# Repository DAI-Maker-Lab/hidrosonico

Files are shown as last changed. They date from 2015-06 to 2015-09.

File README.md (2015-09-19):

# Hidrosónico
<i>Hidrosónico</i> is a stream gauge using a <a href="http://www.maxbotix.com/documents/HRXL-MaxSonar-WR_Datasheet.pdf">MaxSonar HRXL MB7369</a> sonar rangefinder, a <a href="http://www.seeedstudio.com/wiki/Seeeduino-Stalker_v3">Seeeduino Stalker v3</a> Arduino-compatible microcontroller platform, and an <a href="https://learn.adafruit.com/adafruit-fona-mini-gsm-gprs-cellular-phone-module/overview">Adafruit FONA 800</a> GSM module. It reads the distance between the sensor (specifically from where the housing meets the threading) and the water's surface directly below and sends this data at specified intervals to cloud-based storage, SMS, and/or email as determined by the user. It was designed to aid in collection of hydrological data and for flood early warning in developing countries. This version integrates a rain gauge at the request of the recipient. 

The code provided sends data to data.sparkfun.com as the cloud service but it could be easily adapted to any other provider. Please note the places in the code that are marked for user-specific input.

This is a beta unit and we will be making changes as a result of the data and experiences we are collecting from pilot installations in Honduras, as well as feedback from on-the-ground partners like CODEM-DC in Tegucigalpa.

All code and hardware files are being made available under open source licensing. If you use it, please let us know (robert_ryan-silva[at]dai.com), and if you improve it, please share!

##Bill of Materials

Links to vendors are provided for convenience and not meant to imply an endorsement of that vendor; most of the items are available from other sources, and most components can be adequately substituted with equivalents. We have no connections nor receive any benefit from any of the vendors indicated.

###Required:
<ul>
<li><b><a href="http://www.seeedstudio.com/depot/Seeeduino-Stalker-v3-p-1882.html?cPath=6_7">Seeeduino Stalker v3</a></b>. Most Arduino-compatible microcontrollers will work, but most will require additional circuitry to charge the battery from a solar cell and for use of the real-time clock. Some Arduino-compatibles will require some pin changes (though the Arduino Uno and its equivalents should be fine).</li>
<li><b><a href="https://www.adafruit.com/products/1946">Adafruit FONA 800</a> and <a href="https://www.adafruit.com/products/1859">antenna</a></b>. The FONA 808 would also work, but would require some wiring changes and would not fit on the circuit board as designed. Any GSM module that is not based on the SIMCOM SIM 800 series chips would need code changes to work properly.</li>
<li><b><a href="http://www.amazon.com/Maxbotix-MB7369-HRXL-MaxSonar-WRM/dp/B00A7YHBT2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">Maxbotix MaxSonar HRXL MB7369</a></b>.</li>
<li><b>A solar panel</b>. We use <a href="https://www.adafruit.com/products/500">these</a>. We have not found any panels that terminate in the JST connector that the Stalker takes, so a <a href="https://www.adafruit.com/products/261">JST connector</a> is highly recommended; <a href="http://www.amazon.com/gp/product/B0076AY6J8?psc=1&redirect=true&ref_=oh_aui_search_detailpage">Scotchlok butt connectors</a> or similar (inside the enclosure, of course) make connecting the JST connector to the solar panel quite easy.</li>
<li><b>A lithium-ion battery</b>. We use <a href="https://www.adafruit.com/products/1781">these</a>.</li>
</ul>

###Optional:
<ul>
<li><b>Rain gauge</b>. You can collect rainfall data at the same site for a minimal additional cost with the addition of a rain gauge. The <i>Hidrosónico</i> code in the repository records data from a simple <a href="https://www.argentdata.com/catalog/product_info.php?products_id=168">Argent Data Systems rain gauge</a>. You'll need two 1K ohm resistors and a pair of 1N148 diodes to wire it to the microcontroller; an RJ-11 jack <a href="https://www.sparkfun.com/products/132">like this one from Sparkfun</a> will make this easier to work with, but you could strip the wires and solder them directly.</li>
<li><b>Circuit board</b>. Eagle files for a custom circuit board to accommodate the FONA and the optional rain gauge are included in the repository. You could cut this on a CNC machine or have it fabricated by a vendor like <a href="https://oshpark.com/">OSH Park</a>. It isn't strictly necessary -- you could wire the FONA directly -- but we found in practice that installation can be a violent process and connections coming loose is a real possibility. It is recommended especially if you intend to implement the rain gauge.</li>
<li><b>Interior structure</b>. The repository includes a STL file for an interior frame to hold the various internal components stable inside a 4 x 4 x 2 inch PVC junction box <a href=http://www.homedepot.com/p/Carlon-4-in-x-4-in-x-2-in-PVC-Junction-Box-5-Pack-E989NNJ-CAR/202206114">like this one</a>. We cut a 1-inch hole in the faceplate of the junction box and use PVC cement to attach a threaded 3/4-inch coupling <a href="http://www.homedepot.com/p/Carlon-3-4-in-PVC-Coupling-E940E-CTN/100404040">like this one</a>. Again, it's not necessary, but it does keep things from banging around much during installation. Additional holes must be drilled to accommodate the solar panel and the rain gauge. We use plumber's putty to fill the gaps around the cabling.</li>
<li><b>Mounts</b>. You'll want to mount the solar panel and optional rain gauge somehow. The repository includes SVG files for mounts that we have used with the PVC junction boxes. We cut these from sheet metal using waterjet cutters or 3.5mm polypropylene using laser cutters; both have the advantage of being easily bendable (with heat, in the case of polypropylene) to the desired angle. For those without access to fancy CNC cutters, the repository also includes a template for a simpler sheet metal solar panel mount that could be cut with aviation shears or other sheet metal cutting implements.</li>
<li><b><a href="http://www.seeedstudio.com/depot/Grove-4-pin-Female-Jumper-to-Grove-4-pin-Conversion-Cable-5-PCs-per-PAck-p-1020.html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">Grove <-> female jumper cable</a></b>. Makes connecting the MaxBotix to the Stalker very easy indeed.</li>
<li><b>An Xbee 802.15.4 radio</b> will allow you to reprogram the unit from nearby without physically opening the housing, which can be a serious hassle depending on where the unit is mounted.</li>

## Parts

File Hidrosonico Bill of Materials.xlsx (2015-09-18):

Hidrosonico Bill of Materials
Part | Manufacturer Part Number | Vendor Information | Unit Cost | Pieces per Unit | Total Cost
3D Printed Frame | n/a | Custom (PLA) | $0.36 | 1 | $0.36
3M Scotchlok IDC Butt Connector (UY2-3M) | 610373752064 | http://smile.amazon.com/gp/product/B0076AY6J8?psc=1&redirect=true&ref_=oh_aui_detailpage_o00_s00 | $0.10 | 2 | $0.21
Adafruit FONA 800 Mini (uFL) | 1946 | https://www.adafruit.com/products/1946 | $39.95 | 1 | $39.95
Carlon 4"x2" PVC junction box | E989NNJ-CAR | http://www.homedepot.com/p/Carlon-4-in-x-2-in-Junction-Box-E989NNJ-CAR/100404097 | $6.88 | 1 | $6.88
Generic 1kOhm resistors | EP5141K00 | http://smile.amazon.com/gp/product/B00B5R8950?psc=1&redirect=true&ref_=oh_aui_detailpage_o00_s00 | $0.18 | 2 | $0.36
Generic 1N4148 diodes | 1N4148FS-ND | http://www.digikey.com/product-search/en?keywords=1N4148FS-ND | $0.10 | 2 | $0.20
Grove 4-pin Female Jumper to Grove 4-pin Conversion Cable | 110990028 | http://www.seeedstudio.com/depot/Grove-4-pin-Female-Jumper-to-Grove-4-pin-Conversion-Cable-5-PCs-per-PAck-p-1020.html | $0.78 | 1 | $0.78
LiPo battery | 1781 | https://www.adafruit.com/products/1781 | $9.95 | 1 | $9.95
Maxbotix Sonar | MB7369 HRXL-MaxSonar-WRM | http://www.maxbotix.com/Ultrasonic_Sensors/MB7369.htm | $109.95 | 1 | $109.95
Mini GSM/Cellular Quad-Band Antenna - 2dBi SMA Plug | 1859 | https://www.adafruit.com/products/1859 | $4.95 | 1 | $4.95
PCB | n/a | Custom (OSH Park) | $6.60 | 1 | $6.60
Rain gauge | n/a | https://www.argentdata.com/catalog/product_info.php?products_id=168 | $15.00 | 1 | $15.00
Rain gauge mount | n/a | Custom (polypropylene) |  | 1 | $0.00
RJ11 jack | PRT-00132 | https://www.sparkfun.com/products/132 | $1.25 | 1 | $1.25
Scotch Heavy Duty Fasteners | RFD7091 | http://smile.amazon.com/gp/product/B00347A8GM?psc=1&redirect=true&ref_=oh_aui_detailpage_o00_s00 | $2.71 | 1 | $2.71
Seeed Studio Seeeduino Stalker v3 | 102010017 | http://www.seeedstudio.com/depot/Seeeduino-Stalker-v3-p-1882.html?cPath=6_7 | $39.00 | 1 | $39.00
SMA to uFL/u.FL/IPX/IPEX RF Adapter Cable | 851 | https://www.adafruit.com/products/851 | $3.95 | 1 | $3.95
Solar panel (6V 3.4W) | 500 | https://www.adafruit.com/products/500 | $39.00 | 1 | $39.00
Solar panel mount | n/a | Custom (polypropylene) |  | 1 | $0.00
Xbee 802.15.4 1MW w/wire antenna | XB24-AWI-001 | http://www.digikey.com/product-detail/en/XB24-AWI-001/XB24-AWI-001-ND/935965 | $19.00 | 1 | $19.00
Grand Total |  |  |  |  | $300.09

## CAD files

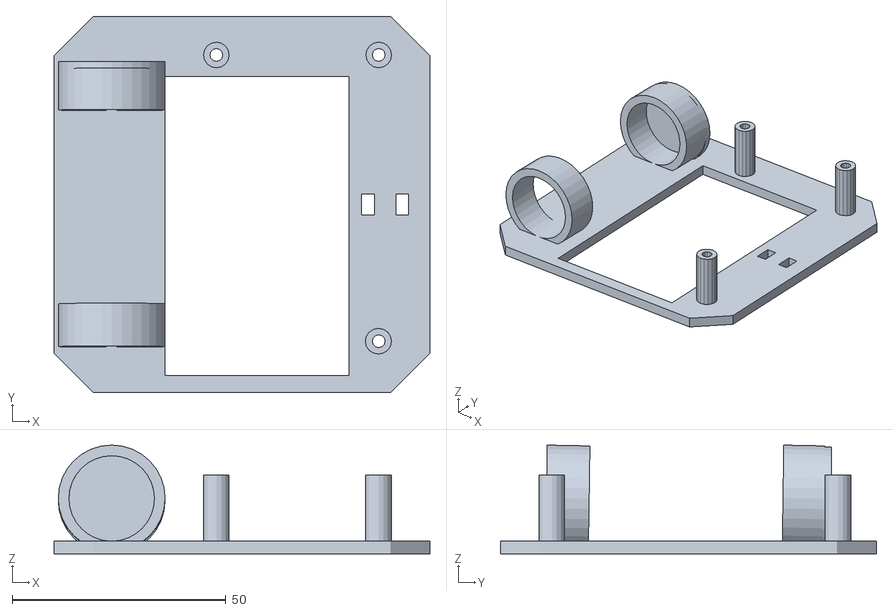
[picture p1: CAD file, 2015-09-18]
hidrosonico_interior_frame.stl
88.0 x 88.0 x 25.5

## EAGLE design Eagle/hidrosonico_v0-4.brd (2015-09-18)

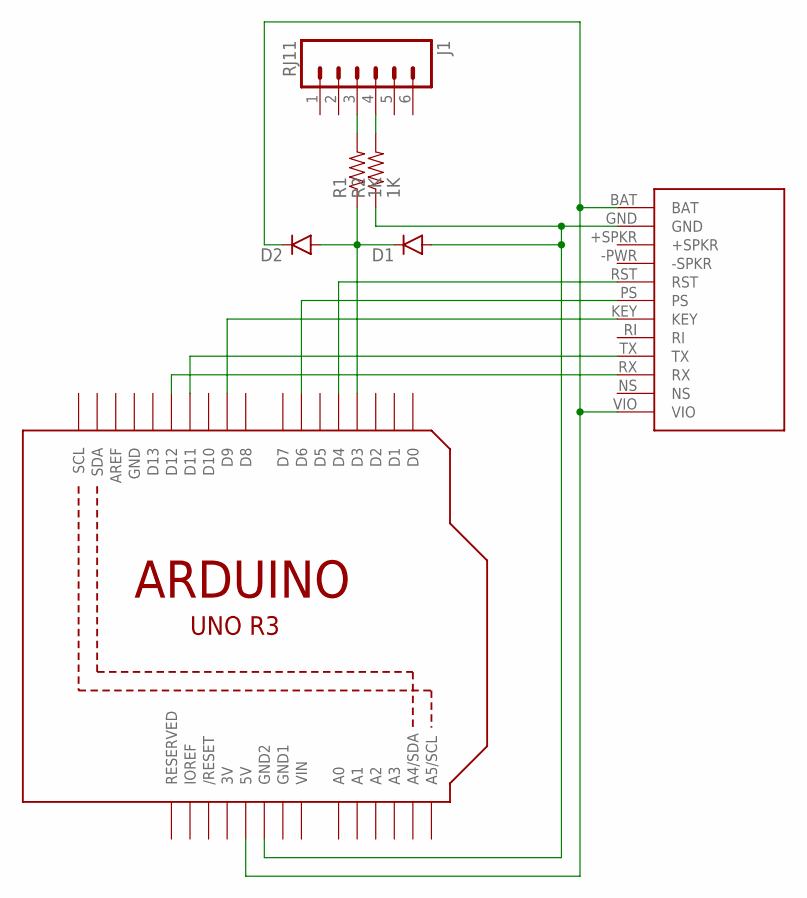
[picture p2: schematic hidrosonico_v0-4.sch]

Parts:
D1, D2: DIODE1N4148; DIODE-1N4148
J1: RJ11; RJ11-6
R1, R2: 1K; AXIAL-0.5
U2: ARDUINOR3-DIMENSION; ARDUINOR3
U$1: ADAFRUIT_FONA800; FONA

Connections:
3V: U2.3V
GND: D1.A, R2.P$1 (1), U2.GND, U2.GND2, U$1.GND
GND1: U2.GND1
unnamed: U2.D4, U$1.RST
unnamed: U2.D6, U$1.PS
unnamed: U2.D9, U$1.KEY
unnamed: U2.D11, U$1.TX
unnamed: U2.D12, U$1.RX
unnamed: J1.3, R1.P$2 (2)
unnamed: D1.C, D2.A, R1.P$1 (1), U2.D3
unnamed: J1.4, R2.P$2 (2)
VCC+: D2.C, U2.5V, U$1.BAT, U$1.VIO
VIN: U2.VIN

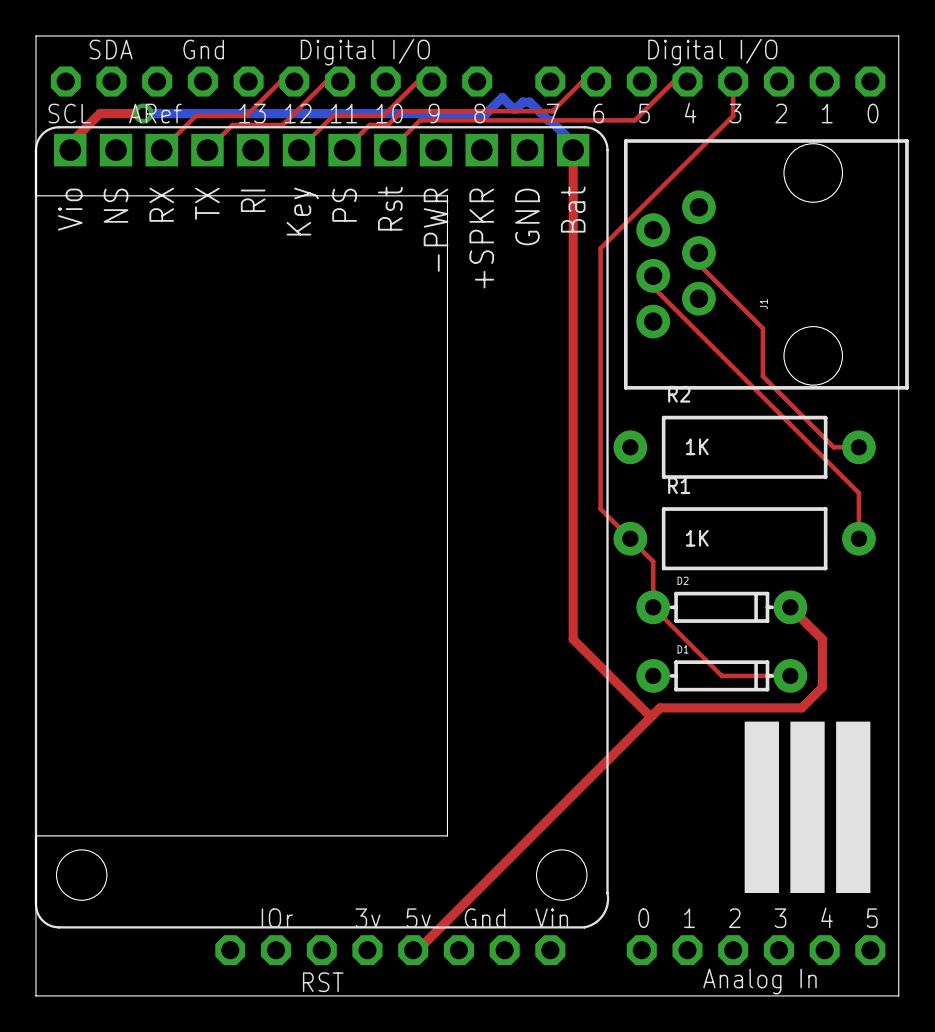
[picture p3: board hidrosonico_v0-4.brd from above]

Board: 2 copper layers, 47.9 x 53.3 mm, 7 parts (0 on the bottom side), 10 nets.

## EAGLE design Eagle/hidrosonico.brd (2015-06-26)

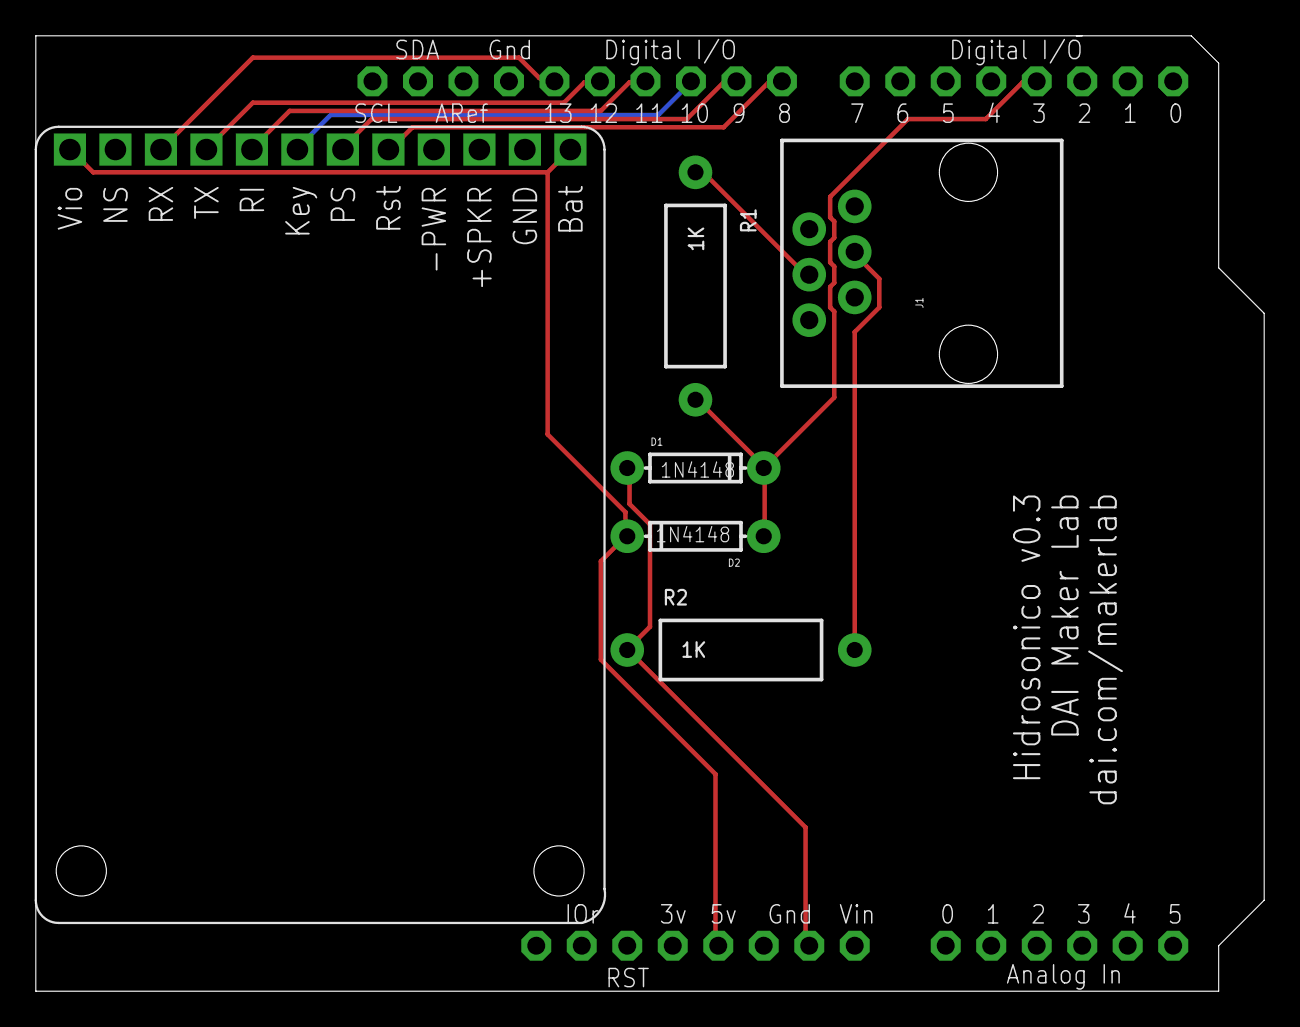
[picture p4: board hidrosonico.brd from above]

Board: 2 copper layers, 68.6 x 53.3 mm, 7 parts (0 on the bottom side), 12 nets.

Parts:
D1, D2: 1N4148; DIODE-1N4148
J1: RJ11; RJ11-6
R1, R2: 1K; AXIAL-0.5
U1: ARDUINOR3-DIMENSION; ARDUINOR3
U$1: ADAFRUIT_FONA; FONA

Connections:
GND: U1.GND, U$1.GND
KEY: U1.D10, U$1.KEY
unnamed: U1.D9, U$1.PS
unnamed: J1.3, R1.P$1
unnamed: D1.A, R2.P$1, U1.GND1
unnamed: D1.C, D2.A, R1.P$2, U1.D3
unnamed: J1.4, R2.P$2
PWR: D2.C, U1.5V, U$1.BAT, U$1.VIO
RI: U1.D11, U$1.RI
RST: U1.D8, U$1.RST
RX: U1.D13, U$1.RX
TX: U1.D12, U$1.TX

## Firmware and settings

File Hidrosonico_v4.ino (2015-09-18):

#define VERSION "0.4-150918.1105"

//- - - - - - - - - - - - - - - - - - - - - - - - - - - - - - - - - - - - - - //
//	These variables must be customized for each unit.

#define UNIT_NAME "HidrosonicoXXXX"          //    Individual name of unit

/* We use the last four digits of the unit's phone number for the unit name, 
in order to more easily keep track of which unit is which.*/

const int HEIGHT = 0;		//	Height of top of octagonal gasket, in cm

//	http://data.sparkfun.com/hidrosonico4631
#define SPARKFUN_PUBLIC_KEY "enter_public_key_here"
#define SPARKFUN_PRIVATE_KEY "enter_private_key_here"

#define TWITTER_GATEWAY "40404"       //      Twitter SMS gateway 

#define UTCoffset -6                  //      Local time offset from UTC. 

/* If your locality implements daylight savings time, this is considerably more
complicated and you'll need changes in the code to accommodate it (provided you
are concerned with local time for things like a midnight reset of rain totals --
if not, you may not care much).*/

const int yellowLevel = 100;                //      Yellow alert level

/* This is the alert level at which we start sending more regular messages.*/

/* We use pulse.to so that we can send SMS messages to changing lists of 
stakeholders without having to change any parameters in the firmware. We'd
love to hear about alternatives!*/

#define MOBILE_GATEWAY "17043237775"         //      pulse.to gateway
const char* pulseTo = "@new_pulsegroup";     //      pulse.to group name

//      Insert your SMTP server settings below

#define SMTPServer "AT+SMTPSRV=\"mail.server.com\",587"
#define SMTPAuthorization "AT+SMTPAUTH=1,\"hidrosonico@domain.com\",\"password\""
#define SMTPFromLine "AT+SMTPFROM=\"hidrosonico@domain.com\",\"Hidrosonico XXXX\""
#define SMTPRecipient "AT+SMTPRCPT=0,0,\"mailgroup@domain.com\",\"Grupo Hidrosonico\""

//- - - - - - - - - - - - - - - - - - - - - - - - - - - - - - - - - - - - - - //

/*	Hidrosónico is a stream gauge using a MaxSonar HRXL MB7369 sonar 
rangefinder, a Seeeduino Stalker v3 Arduino-compatible microcontroller platform, 
and an Adafruit FONA 800 GSM module. It reads the distance between the sensor 
(specifically from where the housing meets the threading) and the water's 
surface directly below and sends this data at specified intervals to cloud-based 
storage, SMS, Twitter and/or email as determined by the user. It was designed to 
aid in collection of hydrological data and for flood early warning in developing 
countries. This version integrates a rain gauge at the request of the recipient. 

The code provided sends data to data.sparkfun.com as the cloud service but it 
could be easily adapted to another provider. 

Please note the section at the beginning of the code that calls for user- and 
unit-specific input.

This is a beta unit and we are actively making changes as a result of 
the data and experiences we are collecting from existing pilot installations 
in Honduras.

This code uses snippets of the Adafruit example code for its FONA library 
(https://github.com/adafruit/Adafruit_FONA_Library) and snippets from the 
Sparkfun example weather station code (https://github.com/sparkfun/Weather_Shield) 
for the rain gauge, both provided under open source licenses or as public domain. 

The remainder of this code is released under the MIT License. You are free to use 
and change this code as you like, provided you retain attribution to Development
Alternatives, Inc. Non-code portions of the project are made available under
the Creative Commons-Attribution (CC BY) license.

If you use it, please let us know (robert_ryan-silva[at]dai.com), and if you 
improve it, please share! */

//	Include programming libraries into the sketch
#include <Adafruit_FONA.h>      //  For Adafruit FONA module
#include <SoftwareSerial.h>	//  For serial communication with FONA
#include <Wire.h>		//  I2C library for communication with RTC
#include <Sleep_n0m1.h>		//  Sleep library
#include <DS1337.h>		//  For the Stalker's real-time clock (RTC)

//	Define pins for various functions
#define rtcInt 0		//  Interrupt number associated with rtcPin
#define rainInt 1		//  Interrupt number associated with rainPin
#define rtcPin 2		//  Interrupt pin from RTC
#define rainPin 3   	        //  Set rain gauge pin

#define pwPin 7  		//  Pulse width data pin from sonar
#define rangePin 8              //  Sonar ranging start/stop pin

#define beePin 5                //  Pin to turn XBee on/off

#define FONA_RST 4 	        //  FONA reset pin
#define FONA_PS 6	        //  Power status pin
#define FONA_KEY 9	        //  On/off pin
#define FONA_TX 11	        //  Receive from FONA
#define FONA_RX 12	        //  Send to FONA

//	Define variables that the sketch will use
int streamHeight = 0;

/* We will create variables to hold  values for the time and date from the RTC. */

byte currentHour;		
byte currentMinute;		  
byte currentDay;
byte currentMonth;
int currentYear;

boolean yellow = false;        //  This cycle's yellow alert
boolean lastYellow = false;    //  Last cycle's yellow alert
boolean alertToday = false;    //  Whether an alert has been sent today
boolean readSuccess = false;   //  Whether the unit is returning a plausible reading

//  For debugging, we'll track the clock acquisition method -- see clockSet()

char method = 0;                

unsigned int action = 0;        //  Tracking the reading/upload number
int failedUploads = 0;

volatile unsigned long raintime, rainlast, raininterval;
volatile float dailyRain = 0;  	//  Rain in mm so far today in local time
volatile float hourlyRain = 0;	//  Rain in mm over the last hour

int pulse;			//  The pulse return length for the sonar
int pulseMode;                  //  The mode of pulses
byte arraysize = 7; 		//  Array for median sonar values (must be odd)
int rangevalue[] = { 0, 0, 0, 0, 0, 0, 0 };	//	Initial array for sonar

//  Configure the software serial interface to FONA

SoftwareSerial fonaSerial = SoftwareSerial(FONA_TX, FONA_RX);
Adafruit_FONA fona = Adafruit_FONA(FONA_RST);

DS1337 RTC;			//  Create the DS1337 real-time clock (RTC) object
Sleep sleep;			//  Create the sleep object



static void rainIRQ()
{
	raintime = millis();  			//  Set raintime to current time
	raininterval = raintime - rainlast;	//  Calculate interval between events
	if (raininterval > 10)  		//  Ignore switch-bounce glitches less
		                                //	than 10mS after initial edge
	{
		dailyRain += .2794;      //  Each dump is .2794mm of rain
		hourlyRain += .2794;  	//  Increase this hour's amount of rain
		rainlast = raintime; 	//  Set up for next event
		Serial.println(F("Rain event."));  //  For debugging
	}
}



static void rtcIRQ()
{
	//	This is a blank interrupt -- we're just using it to wake up.
}



void setup()
{
	Serial.begin(57600);		//  Begin the Serial interface -- using XBee baud rate

	Serial.println(F("Setup begins."));

	ADCSRA = 0;  			//  Disable analog-digital converter for power savings
	Wire.begin();			//  Begin the I2C interface
	RTC.begin();			//  Begin the RTC

	Serial.print(F("Hidrosonico online. Version "));
        Serial.println(VERSION);

	pinMode(pwPin, INPUT);	        //  Sonar pulse width pin
        pinMode(rangePin, OUTPUT);      //  Sonar range start/stop pin
        pinMode(beePin, OUTPUT);        //  Pin controlling power to XBee
	pinMode(FONA_KEY, OUTPUT);      //  The Key pin from the FONA
	pinMode(FONA_PS, INPUT);        //  The Power Status pin from the FONA
	pinMode(rainPin, INPUT_PULLUP); //  The signal pin from the rain gauge

        /*  We experimented with turning ranging off between readings, but it was unclear
        that it was saving much power and it seemed to be interfering with some of the readings.
        It may be worth testing in a future version, but for now we'll just leave it on.*/

//        digitalWrite(rangePin, LOW);    //  Turn ranging off
        digitalWrite(rangePin, HIGH);    //  Turn ranging on
        
	delay(1000);		        

	//	Try up to five times to boot the FONA module.

	byte attempts = 0;
	boolean booted = false;
	while(attempts < 5 && booted == false)
	{
		attempts++;
		if(bootFona() == false)		//  Start the FONA
		{
			booted = false;
		}
		else
		{
			booted = true;
                        Serial.println(F("FONA booted successfully."));
		}
	}
	
        if(booted == false)
        {
                Serial.println(F("FONA boot failed. Check connections."));
        }

//	fona.sendCheckReply(F("ATZ"), F("OK"));		//  Revert to last saved settings

	clockSet();	//  Set the RTC
	stopFona();	//  Turn off the FONA to save power

	DateTime now = RTC.now(); 		 //  Get the current date/time from RTC
	Serial.print(F("The current RTC time is "));
	Serial.print(now.hour(), DEC);
	Serial.print(F(":"));
	Serial.println(now.minute(), DEC);

	RTC.enableInterrupts(EveryMinute);	 //  RTC will interrupt every minute
	RTC.clearINTStatus();                    //  Clear any outstanding interrupts

	attachInterrupt(rainInt, rainIRQ, FALLING);
	attachInterrupt(rtcInt, rtcIRQ, FALLING);
	interrupts();					//  Activate interrupts

	Serial.println(F("Setup complete."));
}



void loop()
{
	DateTime now = RTC.now(); 	//  Get the current date/time

	Serial.print(now.hour());       //  For debugging, print the time
	Serial.print(F(":"));
	Serial.println(now.minute());

	Serial.flush();			//  Give Serial a chance to catch up before sleep

	//	If this is a fifteenth minute, take and upload a reading.

	if(now.minute() % 15 == 0)
	{       
                boolean dataSent = false;               //  Put the flag down
  
		currentHour = now.hour();      
		currentMinute = now.minute();  
		currentDay = now.date();       
		currentMonth = now.month();
		currentYear = now.year();

		action++;

                //  We'll turn the XBee on only from 9-6 to save power
                if (currentHour > 9 && currentHour < 14)
                {
                        digitalWrite (beePin, LOW);
                }
                else
                {
                        digitalWrite (beePin, HIGH);
                }

		bootFona();     //  Start the Fona

                /* One of the original field test units, in Corquín, Honduras, sometimes returned spurious 
                negative streamHeights. The non-negative results seemed to be accurate. While we think this was
                a hardware problem, we'll go ahead and retry the reading up to 3 times if the result is a
                negative streamHeight to try to reduce any recurrence. */

                byte readAttempts = 0;  //  Keep track of attempts at reading a non-negative result
                readSuccess = false;    //  Put the flag down
                
                //  We'll make up to three attempts to get a non-negative reading
                while(readAttempts < 3 && readSuccess == false)
		{
                        takeReading();	//  Take a reading
                        readAttempts++;
                }
                
                readAttempts = 0;      //    Reset the counter

		Serial.print(F("streamHeight: "));
		Serial.println(streamHeight);

                if(streamHeight > yellowLevel)    //    Are we at yellow alert?
                {
                        yellow = true;
                }
                else
                {
                        yellow = false;
                }

		//	We will attempt to upload data to the cloud. If the attempt fails,
		//	we will restart the Fona and try again for up to three attempts.

		byte sendAttempts = 0;		//	Reset the counter
		dataSent = false;		//	Reset the flag

		while(dataSent == false && sendAttempts <= 2)
		{
			sendAttempts++;		//	Increment attempt counter

			if(cloudUpload() == false)	//  If upload appears to fail...
			{
				Serial.println(F("Upload failed. Restarting Fona."));
				stopFona();		//  ...shut the FONA off.
				delay(5000);            //  Give the FONA a moment
				bootFona();             //  Reboot.
				dataSent = false;	//  Ensure flag is down
				failedUploads++;	//  Increment fail counter
			}

			else
			{
				dataSent = true;
			}
		}

		/*if(mailCall() == true)		        //	If it's time to send messages...
		{
			sendMail();			//	...send them.
                        sendSMS();
		}*/

		if(currentMinute == 0)	        //	At the top of the hour, after upload...
		{
			hourlyRain = 0;		//	...zero out the hour's rain total
		}

		if(currentHour == 0 && currentMinute == 0)	//	At midnight, after upload...
		{
			dailyRain = 0;          //	...zero out the day's rain total...
                        alertToday = false;     //      ...reset the alert flag
                        clockSet();             //      ...and set the time again -- the RTC loses more time
                                                //      than the datasheet claims.
		}

		stopFona();		        //	Shut down the FONA to save power
                
                lastYellow = yellow;
        }

	RTC.clearINTStatus();			//	Clear the last loop's RTC interrupt
	sleep.pwrDownMode(); 			//	Set sleep mode to Power Down
	Serial.print(F("Sleeping..."));
	Serial.flush();				//	Let Serial catch up before sleep
	sleep.sleepInterrupt(0, FALLING);	//	Sleep

	/* When the RTC interrupt triggers, the sketch will resume the loop here and so go 
        back to the beginning of the loop. */
}



boolean bootFona()
{
	// Power up the FONA if it needs it
	if (digitalRead(FONA_PS) == LOW)
	{
		Serial.print(F("Powering FONA on..."));
		while (digitalRead(FONA_PS) == LOW)
		{
			digitalWrite(FONA_KEY, LOW);
			delay(500);
		}
		digitalWrite(FONA_KEY, HIGH);
		Serial.println(F(" done."));
		delay(500);
	}

	// Start the FONA
	Serial.print(F("Initializing FONA..."));
	fonaSerial.begin(4800);

	// See if the FONA is responding
	if (! fona.begin(fonaSerial))
	{
		Serial.println(F("Couldn't find FONA"));
		return false;
		while (1);
	}
	else
	{
		Serial.println(F("FONA is OK"));

		//	Wait for a valid network
		Serial.print(F("Waiting for GSM network..."));
		while (1)
		{
			uint8_t network_status = fona.getNetworkStatus();
			if (network_status == 1 || network_status == 5) break;
			delay(250);
		}
		Serial.println(F(" done."));

		delay(5000);

		uint8_t rssi = fona.getRSSI();

		if (rssi > 5)
		{
			if (!fona.enableGPRS(true))
			{
				if(fona.GPRSstate() == 1)
				{
					Serial.println(F("GPRS is on."));
				}
				else
				{
					Serial.println(F("Failed to turn GPRS on."));
				}
			}
		}
		else
		{
			Serial.println(F("Can't transmit, network signal strength is poor."));
		}
		return true;
	}
}



void stopFona()
{
	delay(5000);				//	Shorter delays yield unpredictable results

	if (!fona.enableGPRS(false))
	{
		if(fona.GPRSstate() == 1)
		{
			Serial.println(F("Failed to turn GPRS off."));
		}
		else
		{
			Serial.println(F("GPRS is off."));
		}
	}

	delay(500);

	Serial.println(F("Turning off Fona "));
	while(digitalRead(FONA_PS) == HIGH)
	{
		digitalWrite(FONA_KEY, LOW);
	}
	digitalWrite(FONA_KEY, HIGH);

	delay(4000);
}



boolean cloudUpload()
{
        unsigned int vbat = 0;		//  Battery voltage as read by FONA
        
	fona.getBattVoltage(&vbat);	//  Read the battery voltage

        int rawDumps = (dailyRain / .2794);    

        /* We'll tell FONA to get ready for an HTTP GET command. We could use fona.HTTP_GET_START and build a url 
        with sprintf, but this uses a lot less SRAM.*/
        
	fona.sendCheckReply(F("AT+SAPBR=2,1"), F("OK"));
	fona.sendCheckReply(F("AT+SAPBR=1,1"), F("OK"));
	fona.sendCheckReply(F("AT+HTTPINIT"), F("OK"));
	fona.sendCheckReply(F("AT+HTTPPARA=\"CID\",1"), F("OK"));

        //  Now we'll construct the URL to transmit. 
        fona.print(F("AT+HTTPPARA=\"URL\",\"http://data.sparkfun.com/input/"));
        fona.print(SPARKFUN_PUBLIC_KEY);
        fona.print(F("?private_key="));
        fona.print(SPARKFUN_PRIVATE_KEY);
        fona.print(F("&1_numero="));
        fona.print(action);
        fona.print(F("&2_altura="));
        fona.print(streamHeight);
        fona.print(F("&3_lluvia_diaria="));
        fona.print(dailyRain, 1);
        fona.print(F("&4_lluvia_hora="));
        fona.print(hourlyRain, 1);
        fona.print(F("&5_bateria="));
        fona.print(vbat);
        fona.print(F("&6_hora_sistema="));
        fona.print(currentHour);
        fona.print(F(":"));
        
        if(currentMinute < 10)      //    Print a leading zero when necessary (i.e., 6:00 instead of 6:0)
        {
              fona.print(F("0"));
        }
        
        fona.print(currentMinute);
        fona.print(F("&7_clock_method="));
        fona.print(method);
        fona.print(F("&8_raw_dumps="));
        fona.print(rawDumps);
        fona.print(F("&9_upload_failures="));
        fona.print(failedUploads);
        fona.println(F("\""));


//    ...and Serial print the same thing:

        Serial.print(F("AT+HTTPPARA=\"URL\",\"http://data.sparkfun.com/input/"));
        Serial.print(SPARKFUN_PUBLIC_KEY);
        Serial.print(F("?private_key="));
        Serial.print(SPARKFUN_PRIVATE_KEY);
        Serial.print(F("&1_numero="));
        Serial.print(action);
        Serial.print(F("&2_altura="));
        Serial.print(streamHeight);
        Serial.print(F("&3_lluvia_diaria="));
        Serial.print(dailyRain, 1);
        Serial.print(F("&4_lluvia_hora="));
        Serial.print(hourlyRain, 1);
        Serial.print(F("&5_bateria="));
        Serial.print(vbat);
        Serial.print(F("&6_hora_sistema="));
        Serial.print(currentHour);
        Serial.print(F(":"));
        
        if(currentMinute < 10)      //    Print a leading zero when necessary (i.e., 6:00 instead of 6:0)
        {
              Serial.print(F("0"));
        }
        
        Serial.print(currentMinute);
        Serial.print(F("&7_clock_method="));
        Serial.print(method);
        Serial.print(F("&8_raw_dumps="));
        Serial.print(rawDumps);
        Serial.print(F("&9_upload_failures="));
        Serial.print(failedUploads);
        Serial.println(F("\""));
        
	flushFona();
	fona.sendCheckReply(F("AT+HTTPACTION=0"), F("OK"));

	fona.println("AT+HTTPREAD");

	int dataLength = fona.parseInt();      //  HTTPREAD returns the length of the data read and then the data
	int successFail = fona.parseInt();     //  data.sparkfun.com returns "1 success" on a successful upload

	if(successFail = 1)
	{
		Serial.println(F("Upload succeeded."));
		return true;
	}
	else
	{
		Serial.println(F("Upload failed."));
		return false;
	}

	fona.HTTP_GET_end();
}



void takeReading()
{

	Serial.print(F("Taking readings..."));

//        digitalWrite(rangePin, HIGH);    //    Start ranging - future implementation
//
//        /* The Maxbotix only needs 20us to start ranging, but does some filtering based on 
//        adjacent readings, so we'll let it run for five seconds before we start querying it. */
//
//        delay(5000);        
 
	//	Fill the array with readings
	for(int readingCount = 0; readingCount < arraysize; readingCount++)
	{
		/* The MaxSonar measures the distance of objects by bouncing a
	        superaudible pulse off the object and measuring the time of flight
		(TOF) between the emission of the pulse and its return. For the
		MB7369, 1 microsecond TOF = 1mm of distance. For more see:
		http://www.maxbotix.com/articles/085-pt5.htm#codes
		*/

		Serial.print(F("Reading "));
		Serial.print(readingCount);
		Serial.print(F(": "));

		pulse = pulseIn(pwPin, HIGH);		//	Returns length of pulse in us

		Serial.println(pulse);

		rangevalue[readingCount] = pulse;
		delay(10);				//	Short delay before next pulse reading
	}

//        digitalWrite(rangePin, LOW);          //    Turn sonar off - future implementation
        digitalWrite(rangePin, HIGH);          //    We'll leave ranging on
        
	//	Take mode of readings to smooth out any errors or noise
	pulseMode = mode(rangevalue, arraysize);

	Serial.print(F("pulseMode: "));
	Serial.println(pulseMode);

	streamHeight = HEIGHT - (pulseMode / 10);

        if(streamHeight < 0)
        {
                readSuccess = false;
        }
        else
        {
                readSuccess = true;
        }

	Serial.println(F("done."));
	delay(5000);
}



int mode(int * x, int n)    //  Calculate the mode of an array of readings
{
	int i = 0;
	int count = 0;
	int maxCount = 0;
	int mode = 0;

	int bimodal;
	int prevCount = 0;
	while(i < (n - 1))
	{
		prevCount = count;
		count = 0;
		while(x[i] == x[i + 1])
		{
			count++;
			i++;
		}
		if(count > prevCount & count > maxCount)
		{
			mode = x[i];
			maxCount = count;
			bimodal = 0;
		}
		if(count == 0)
		{
			i++;
		}
		if(count == maxCount) 		//	If the dataset has 2 or more modes
		{
			bimodal = 1;
		}
		if(mode == 0 || bimodal == 1) 	//	Return the median if no mode
		{
			mode = x[(n / 2)];
		}
		return mode;
	}
}
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

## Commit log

2015-06-26 Add non-text files to repository
    [hidrosonico.brd, hidrosonico.sch, hidrosonico_interior_frame.stl]
2015-07-07 Update hidrosonico.ino
    Implement changes resulting from pilot installation feedback: improved clockSet(), streamHeight-dependent message scheduling logic, negative streamHeight filtering, and reduced SRAM usage.
2015-09-18 Updated Eagle board file
    Improved PCB design includes easier access to SIM slot on FONA and
    battery and solar jacks on Stalker.
    [hidrosonico.sch, hidrosonico_interior_frame.stl, hidrosonico_v0-4.brd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]
2015-09-18 Added Bill of Materials
    [Hidrosonico Bill of Materials.xlsx]

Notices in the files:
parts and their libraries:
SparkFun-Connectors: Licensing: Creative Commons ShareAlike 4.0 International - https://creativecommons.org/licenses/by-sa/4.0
